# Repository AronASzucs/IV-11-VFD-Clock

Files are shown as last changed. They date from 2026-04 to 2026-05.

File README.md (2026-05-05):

<h1 align="center">IV-11 VFD Tube Clock</h1>

<p align="center">
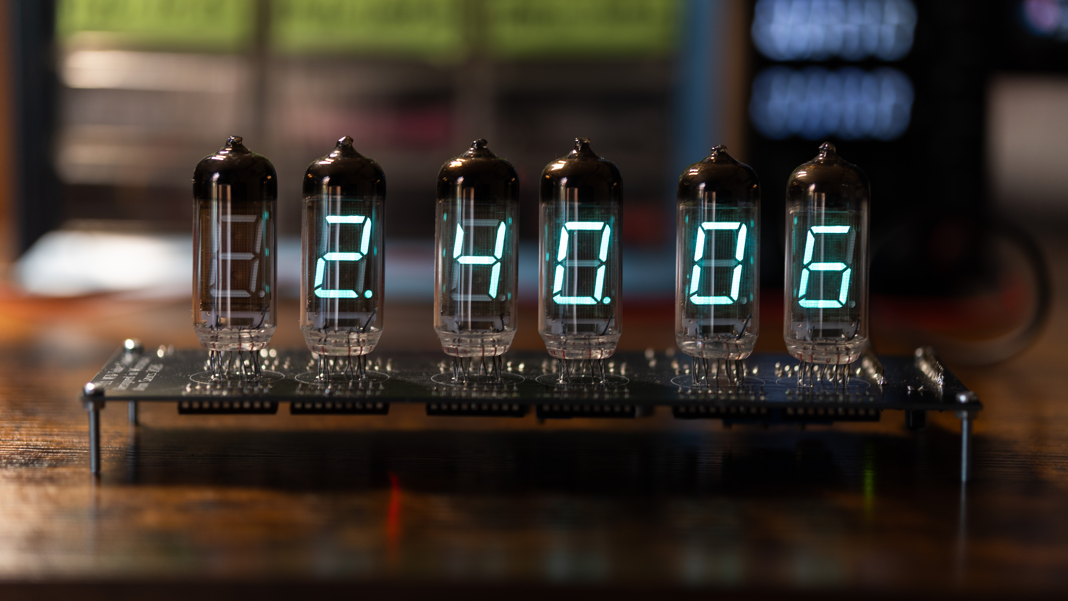
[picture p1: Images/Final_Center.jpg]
  
</p>

<p align="center">
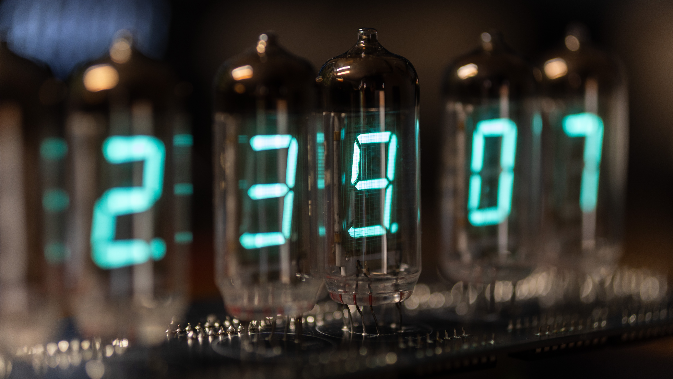
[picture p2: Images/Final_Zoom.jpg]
  
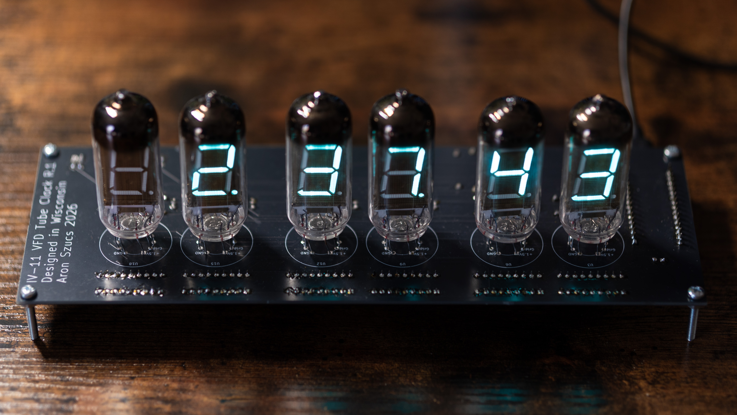
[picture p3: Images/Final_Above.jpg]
  
</p>

---

## Overview

A 6-digit clock built around Soviet-era IV-11 vacuum fluorescent display tubes, vintage components manufactured in Ukraine during the 1970s-80s. The entire project was designed from scratch, including schematic design, custom PCB layout, and firmware, with no kit or reference design used beyond architectural inspiration.

---

## Hardware

**Display**
6x IV-11 7-segment VFD tubes driven in a static configuration. One dedicated 74HC595N shift register and UDN2981A high-voltage source driver per tube, all daisy-chained via SPI. Static drive means every tube is on simultaneously at full brightness with no multiplexing.

**Power Supply**
The clock runs entirely from a 5V USB source with two onboard switching converters:
- XL6009 boost converter stepping 5V → 25V for the anode and grid rails
- LM2596 buck converter stepping 5V → 1.5V for the tube filament rails

**Timekeeping**
DS3231 real-time clock module over I2C with CR2032 battery backup. Accurate to ±2ppm and loses less than one minute per year.

**Microcontroller**
Arduino Nano Every handling SPI display control, I2C RTC communication, PWM brightness via shift register OE pin, button input with hardware debounce, and EEPROM-persistent user settings.

<p align="center">
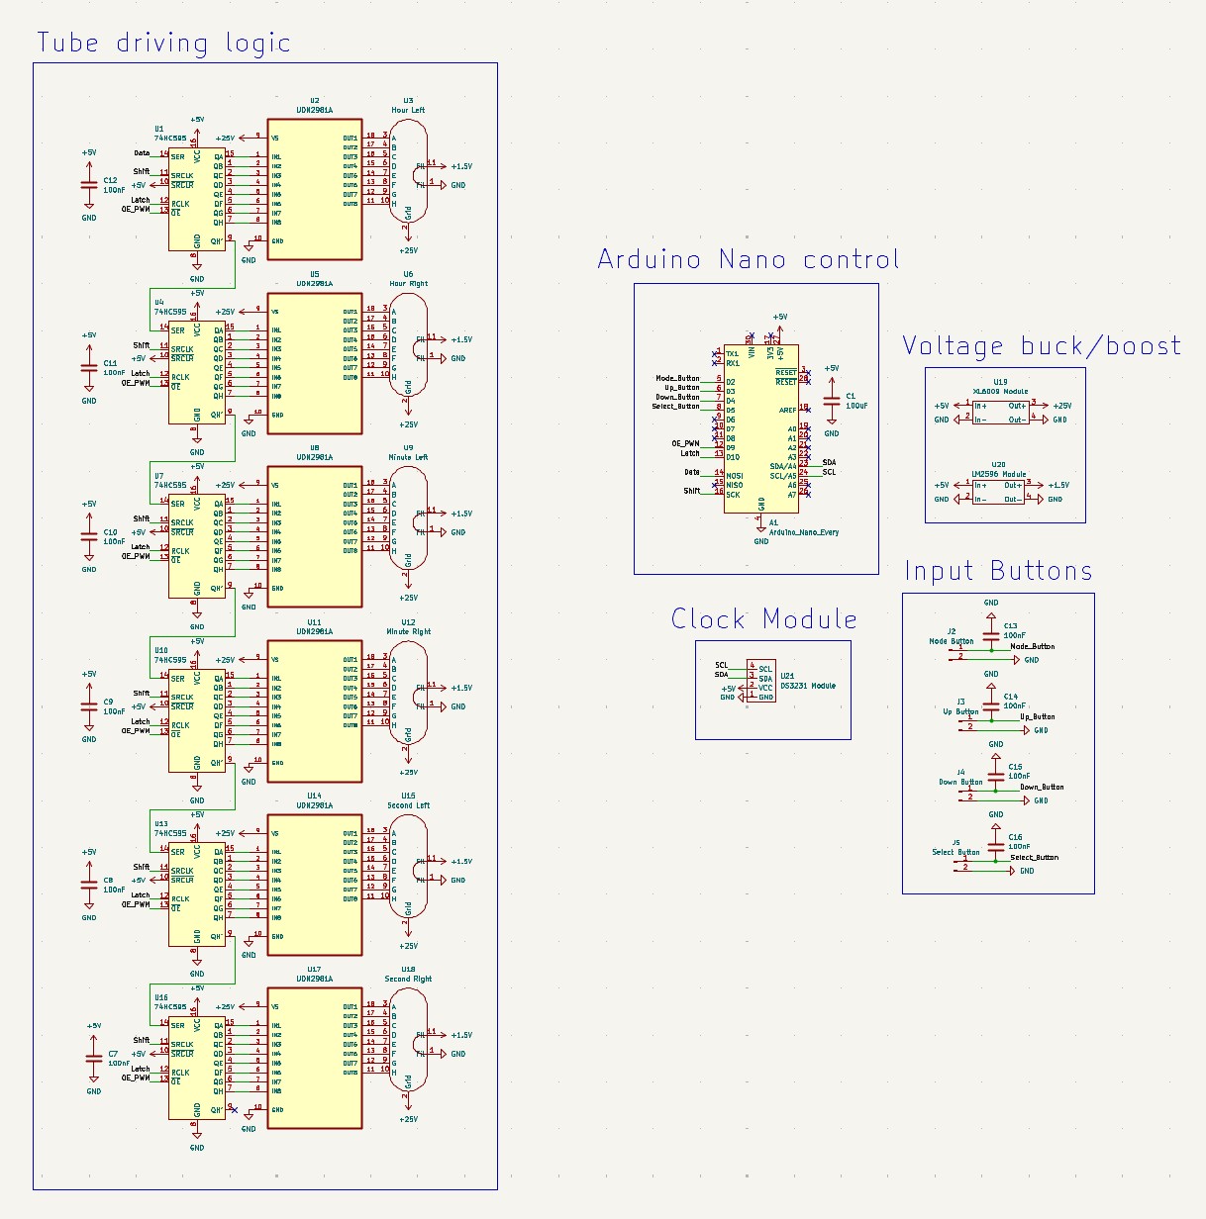
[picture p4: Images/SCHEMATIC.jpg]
  
</p>

---

## Firmware

The clock firmware implements a 7-state FSM for all user interaction:

| Mode | Function |
|---|---|
| 0 | Normal clock display |
| 1 | Set hours |
| 2 | Set minutes |
| 3 | Set seconds |
| 4 | Manual brightness (1–9) |
| 5 | Auto-brightness on/off |
| 6 | 12/24hr toggle |

Features include PWM brightness control via the 74HC595 OE pin, automatic-brightness scheduling by hour of day, hardware debounce capacitors on all button inputs, and full EEPROM persistence for brightness, auto-brightness, and 12/24hr preference across power cycles.

---

## PCB

2-layer board designed in KiCad, fabricated by JLCPCB. Custom symbols and footprints created for the IV-11 tubes, XL6009 boost converter, and LM2596 buck converter modules. Ground plane on the bottom copper layer. Power traces sized for current capacity: 1.0mm for the 600mA filament rail and 0.5mm for the 25V anode rail.

<p align="center">
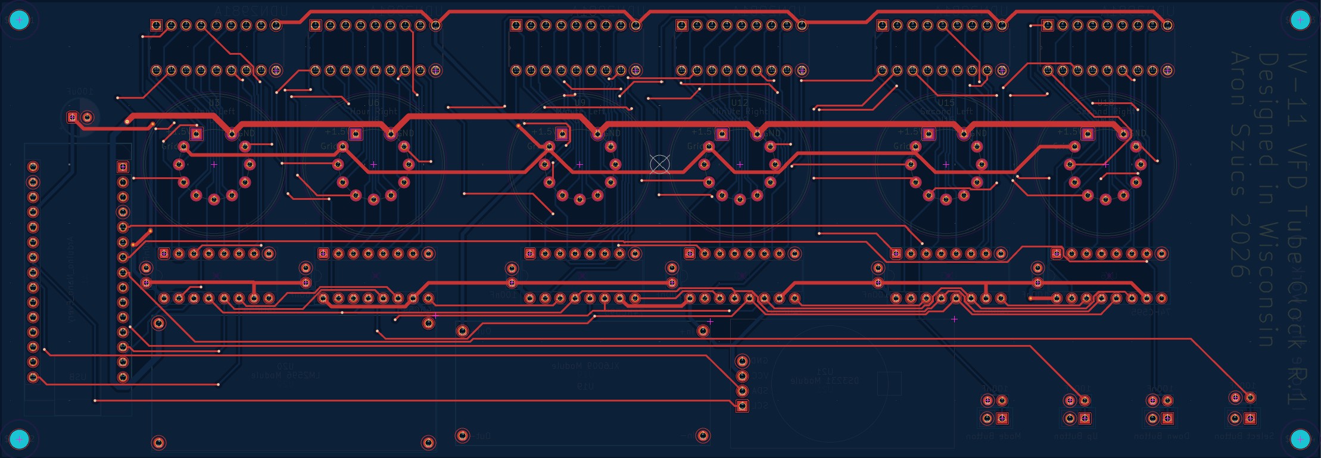
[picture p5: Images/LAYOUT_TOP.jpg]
  
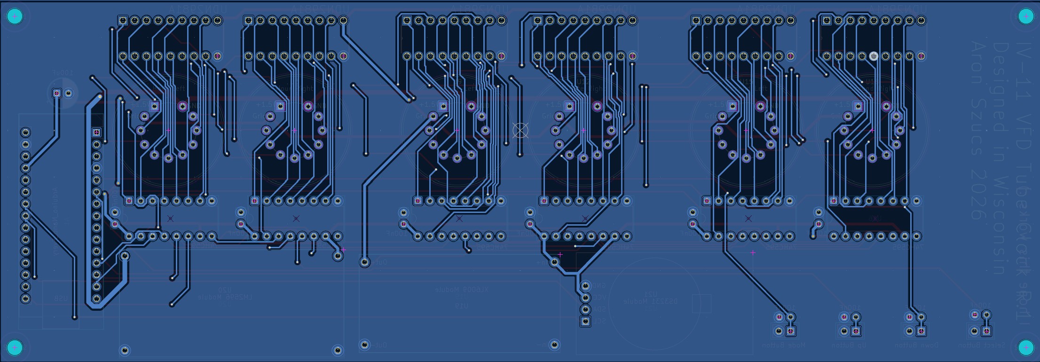
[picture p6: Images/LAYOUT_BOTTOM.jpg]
  
</p>

<p align="center">
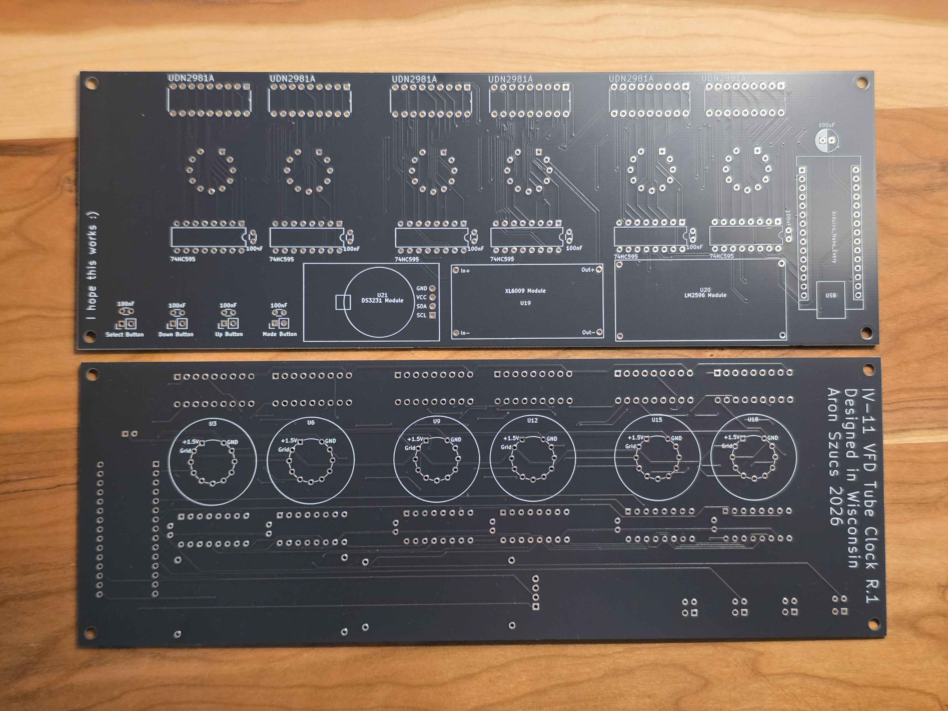
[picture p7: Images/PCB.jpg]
  
</p>

---

## Design Decisions
- I chose a static drive architecture over multiplexing for driving the VFD tubes to prioritize maximum tube brightness. Multiplexing would have reduced the total IC count substantially, but static drive increases perceived brightness and simplifies the firmware significantly.
- I used standalone pre-made buck and boost converter modules rather than integrating discrete switching converter circuits directly into the PCB to reduce design complexity on a first revision. These modules are cheap and if one fails in the future it can be swapped out easily.
- Instead of an ESP32 I used an Arduino Nano Every because this project does not require Bluetooth or WiFi. It is a simple clock after all. This did mean manual time-setting functionality needed to be implemented, which I handled by designing a 7-state FSM with full time adjustment settings. The ESP32 also runs at 3.3V which would have introduced an additional voltage level to manage.
- I encountered button signal bouncing during breadboard prototyping, so I added hardware debouncing via 100nF capacitors on each button GPIO pin in addition to software debouncing. The combination made false presses essentially nonexistent.
- I really wanted to add brightness control to my clock so it's not extremely bright at night, so I came up with the idea of toggling the output enable signal of the shift registers from a variable PWM from the Arduino Nano Every. The end result is a clean, software-driven brightness control.
- To improve signal integrity and simplify routing, I poured a solid ground plane across the entire bottom copper layer of the PCB rather than routing individual ground traces.

<p align="center">
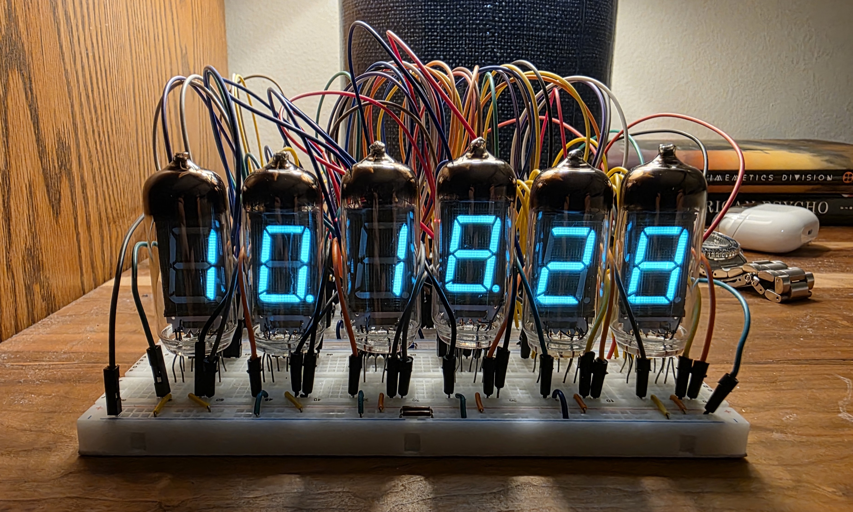
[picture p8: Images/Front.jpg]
  
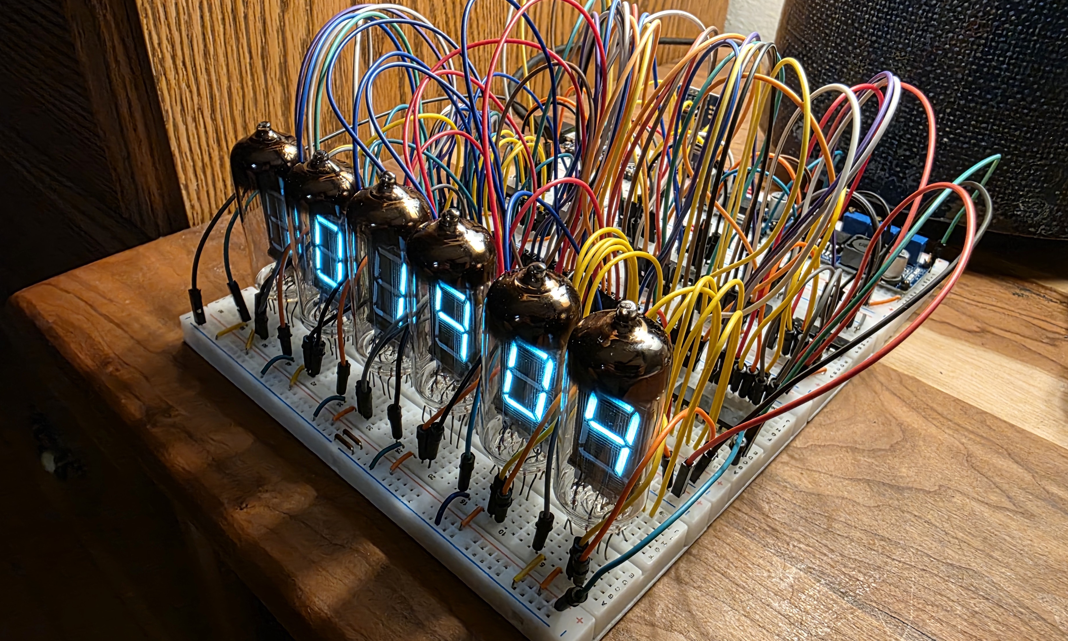
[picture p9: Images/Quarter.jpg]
  
</p>

---

## Build Notes

- The IV-11 tubes arrived from Ukraine after ~5 weeks in transit
- A tube tester utility was written to map each shift register bit to its physical segment before finalizing the digit lookup table
- The tube footprint was initially mirrored due to a bottom-view vs top-view convention mismatch in an online reference, which I caught before ordering and corrected
- This is my first major PCB design and the first revision worked flawlessly
- Production-ready Gerber files are included in the `Gerbers` folder. 

---

## Cost

| Component | Source | Cost |
|---|---|---|
| IV-11 tubes × 6 | eBay | $40.09 |
| PCB × 5 | JLCPCB | $22.84 |
| Buttons × 6 | AliExpress | $6.93 |
| Screws and hex nuts | Hardware Store | $6.25 |
| UDN2981A × 10 | AliExpress | $3.39 |
| XL6009 modules × 3 | AliExpress | $2.99 |
| DS3231 RTC module | AliExpress | $2.19 |
| LM2596 modules × 2 | AliExpress | $1.59 |
| 74HC595N × 10 | AliExpress | $1.19 |
| Arduino Nano Every | University | Free |
| Capacitors, resistors, headers | University | Free |
| **Total** | | **$87.46** |

## Acknowledgements

*Inspired by [OpenVFD](https://www.instructables.com/OpenVFD-6-Digit-IV-11-VFD-Tube-Clock/) for the static drive architecture using 74HC595 shift registers and UDN2981A source drivers.*

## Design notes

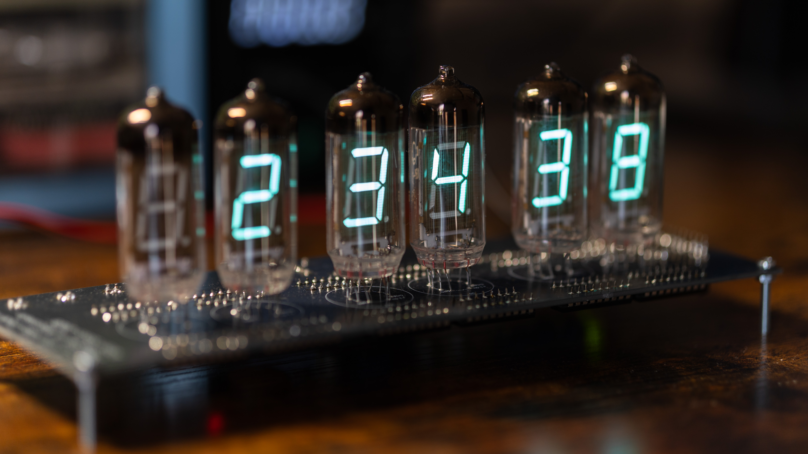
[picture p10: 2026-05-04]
Images/Final_Quarter.jpg

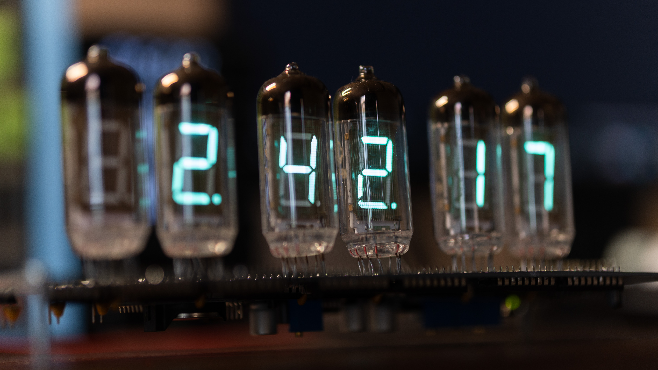
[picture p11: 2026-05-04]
Images/Final_Bottom.jpg

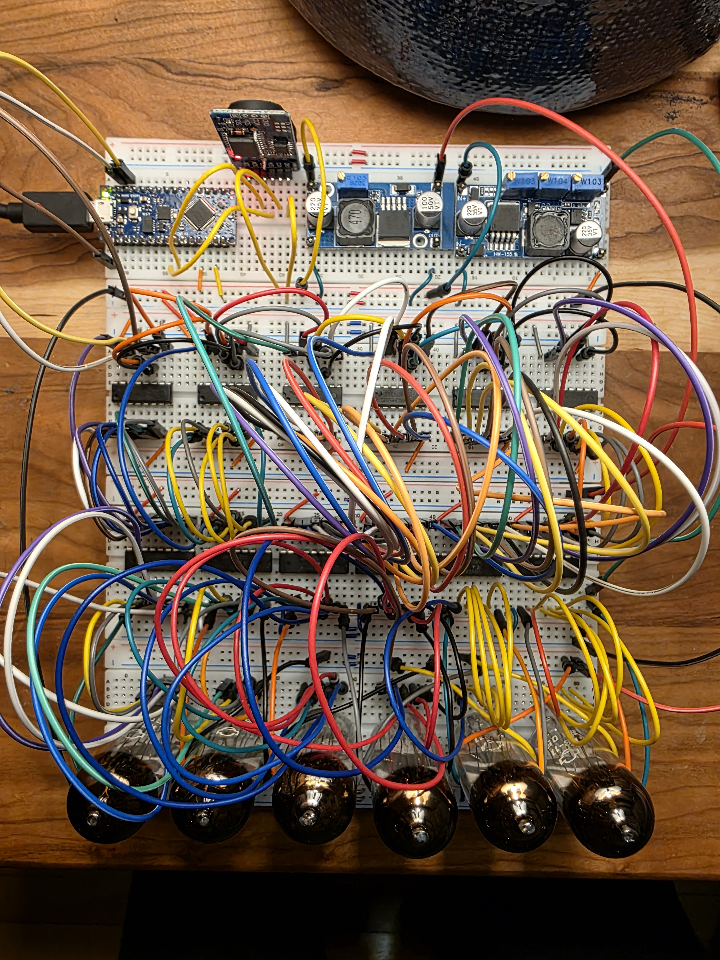
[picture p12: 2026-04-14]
Images/Above.jpg

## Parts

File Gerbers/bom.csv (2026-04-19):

Designator | Footprint | Quantity | Value | LCSC Part #
A1 | Arduino_Nano | 1 | Arduino_Nano_Every
C1 | CP_Radial_D6.3mm_P2.50mm | 1 | 100uF
C10, C11, C12, C13, C14, C15, C16, C7, C8, C9 | C_Disc_D3.0mm_W1.6mm_P2.50mm | 10 | 100nF
J2 | PinHeader_1x02_P2.54mm_Vertical | 1 | Mode Button
J3 | PinHeader_1x02_P2.54mm_Vertical | 1 | Up Button
J4 | PinHeader_1x02_P2.54mm_Vertical | 1 | Down Button
J5 | PinHeader_1x02_P2.54mm_Vertical | 1 | Select Button
U1, U10, U13, U16, U4, U7 | DIP-16_W7.62mm | 6 | 74HC595
U11, U14, U17, U2, U5, U8 | DIP254P762X533-18 | 6 | UDN2981A | UDN2981A
U12 | IV-11 VFD Tube | 1 | Minute Right
U15 | IV-11 VFD Tube | 1 | Second Left
U18 | IV-11 VFD Tube | 1 | Second Right
U19 | XL6009 Module | 1 | XL6009 Module
U20 | LM2596 Module | 1 | LM2596 Module
U21 | DS3231 Module | 1 | DS3231 Module
U3 | IV-11 VFD Tube | 1 | Hour Left
U6 | IV-11 VFD Tube | 1 | Hour Right
U9 | IV-11 VFD Tube | 1 | Minute Left

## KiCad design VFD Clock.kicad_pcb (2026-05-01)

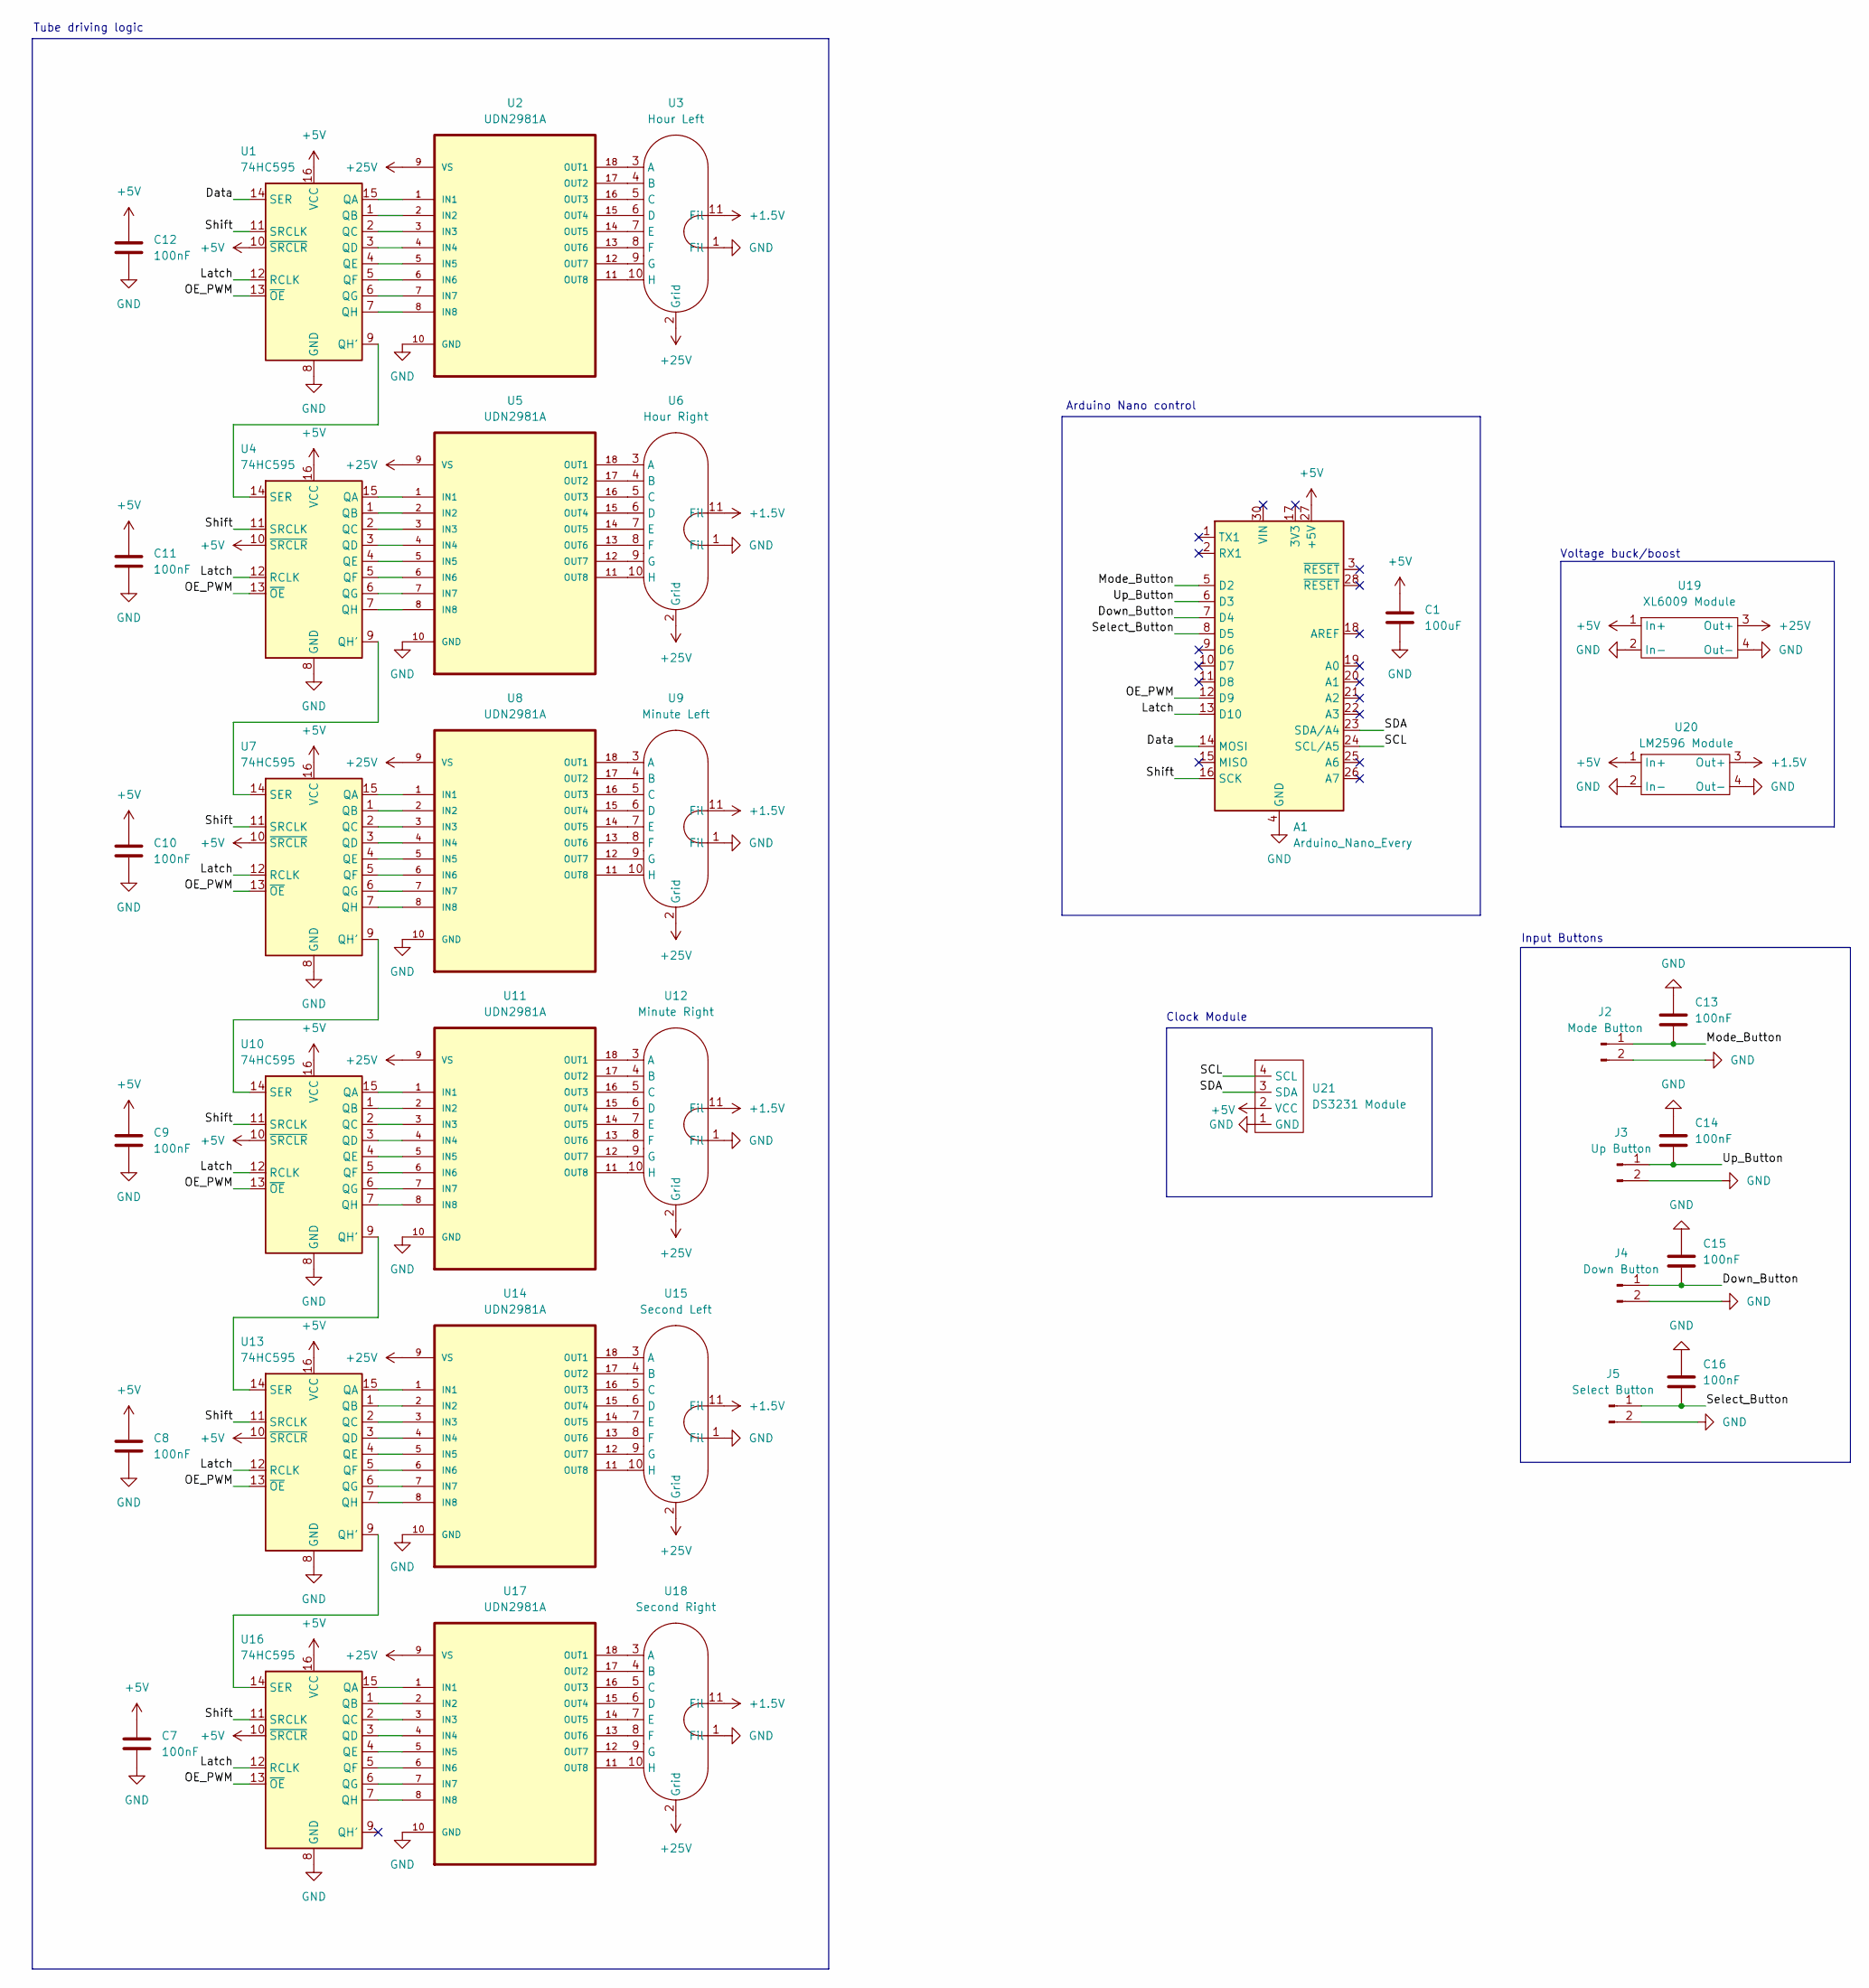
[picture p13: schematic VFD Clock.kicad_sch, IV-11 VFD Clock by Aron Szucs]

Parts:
A1: Arduino_Nano_Every; Arduino_Nano
C1: 100uF; CP_Radial_D6.3mm_P2.50mm
C7, C8, C9, C10, C11, C12, C13, C14, C15, C16: 100nF; C_Disc_D3.0mm_W1.6mm_P2.50mm
J2: Mode Button; PinHeader_1x02_P2.54mm_Vertical
J3: Up Button; PinHeader_1x02_P2.54mm_Vertical
J4: Down Button; PinHeader_1x02_P2.54mm_Vertical
J5: Select Button; PinHeader_1x02_P2.54mm_Vertical
U1, U4, U7, U10, U13, U16: 74HC595; DIP-16_W7.62mm
U2, U5, U8, U11, U14, U17: UDN2981A; DIP254P762X533-18; MPN UDN2981A
U3: Hour Left; IV-11 VFD Tube
U6: Hour Right; IV-11 VFD Tube
U9: Minute Left; IV-11 VFD Tube
U12: Minute Right; IV-11 VFD Tube
U15: Second Left; IV-11 VFD Tube
U18: Second Right; IV-11 VFD Tube
U19: XL6009 Module
U20: LM2596 Module
U21: DS3231 Module

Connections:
+1.5V: U3.11 (Fil), U6.11 (Fil), U9.11 (Fil), U12.11 (Fil), U15.11 (Fil), U18.11 (Fil), U20.3 (Out+)
+5V: A1.27 (+5V), C1.1, C7.1, C8.1, C9.1, C10.1, C11.1, C12.1, U1.10 (~SRCLR), U1.16 (VCC), U4.10 (~SRCLR), U4.16 (VCC), U7.10 (~SRCLR), U7.16 (VCC), U10.10 (~SRCLR), U10.16 (VCC), U13.10 (~SRCLR), U13.16 (VCC), U16.10 (~SRCLR), U16.16 (VCC), U19.1 (In+), U20.1 (In+), U21.2 (VCC)
+25V: U2.9 (VS), U3.2 (Grid), U5.9 (VS), U6.2 (Grid), U8.9 (VS), U9.2 (Grid), U11.9 (VS), U12.2 (Grid), U14.9 (VS), U15.2 (Grid), U17.9 (VS), U18.2 (Grid), U19.3 (Out+)
/Data: A1.14 (MOSI), U1.14 (SER)
/Down_Button: A1.7 (D4), C15.2, J4.1
/Latch: A1.13 (D10), U1.12 (RCLK), U4.12 (RCLK), U7.12 (RCLK), U10.12 (RCLK), U13.12 (RCLK), U16.12 (RCLK)
/Mode_Button: A1.5 (D2), C13.2, J2.1
/OE_PWM: A1.12 (D9), U1.13 (~OE), U4.13 (~OE), U7.13 (~OE), U10.13 (~OE), U13.13 (~OE), U16.13 (~OE)
/SCL: A1.24 (SCL/A5), U21.4 (SCL)
/SDA: A1.23 (SDA/A4), U21.3 (SDA)
/Select_Button: A1.8 (D5), C16.2, J5.1
/Shift: A1.16 (SCK), U1.11 (SRCLK), U4.11 (SRCLK), U7.11 (SRCLK), U10.11 (SRCLK), U13.11 (SRCLK), U16.11 (SRCLK)
/Up_Button: A1.6 (D3), C14.2, J3.1
GND: A1.4 (GND), A1.29 (GND), C1.2, C7.2, C8.2, C9.2, C10.2, C11.2, C12.2, C13.1, C14.1, C15.1, C16.1, J2.2, J3.2, J4.2, J5.2, U1.8 (GND), U2.10 (GND), U3.1 (Fil), U4.8 (GND), U5.10 (GND), U6.1 (Fil), U7.8 (GND), U8.10 (GND), U9.1 (Fil), U10.8 (GND), U11.10 (GND), U12.1 (Fil), U13.8 (GND), U14.10 (GND), U15.1 (Fil), U16.8 (GND), U17.10 (GND), U18.1 (Fil), U19.2 (In-), U19.4 (Out-), U20.2 (In-), U20.4 (Out-), U21.1 (GND)
unnamed: U1.15 (QA), U2.1 (IN1)
unnamed: U1.1 (QB), U2.2 (IN2)
unnamed: U1.2 (QC), U2.3 (IN3)
unnamed: U1.3 (QD), U2.4 (IN4)
unnamed: U1.4 (QE), U2.5 (IN5)
unnamed: U1.5 (QF), U2.6 (IN6)
unnamed: U1.6 (QG), U2.7 (IN7)
unnamed: U1.9 (QH'), U4.14 (SER)
unnamed: U1.7 (QH), U2.8 (IN8)
unnamed: U2.18 (OUT1), U3.3 (A)
unnamed: U2.17 (OUT2), U3.4 (B)
unnamed: U2.16 (OUT3), U3.5 (C)
unnamed: U2.15 (OUT4), U3.6 (D)
unnamed: U2.14 (OUT5), U3.7 (E)
unnamed: U2.13 (OUT6), U3.8 (F)
unnamed: U2.12 (OUT7), U3.9 (G)
unnamed: U2.11 (OUT8), U3.10 (H)
unnamed: U4.15 (QA), U5.1 (IN1)
unnamed: U4.1 (QB), U5.2 (IN2)
unnamed: U4.2 (QC), U5.3 (IN3)
unnamed: U4.3 (QD), U5.4 (IN4)
unnamed: U4.4 (QE), U5.5 (IN5)
unnamed: U4.5 (QF), U5.6 (IN6)
unnamed: U4.6 (QG), U5.7 (IN7)
unnamed: U4.9 (QH'), U7.14 (SER)
unnamed: U4.7 (QH), U5.8 (IN8)
unnamed: U5.18 (OUT1), U6.3 (A)
unnamed: U5.17 (OUT2), U6.4 (B)
unnamed: U5.16 (OUT3), U6.5 (C)
unnamed: U5.15 (OUT4), U6.6 (D)
unnamed: U5.14 (OUT5), U6.7 (E)
unnamed: U5.13 (OUT6), U6.8 (F)
unnamed: U5.12 (OUT7), U6.9 (G)
unnamed: U5.11 (OUT8), U6.10 (H)
unnamed: U7.15 (QA), U8.1 (IN1)
unnamed: U7.1 (QB), U8.2 (IN2)
unnamed: U7.2 (QC), U8.3 (IN3)
unnamed: U7.3 (QD), U8.4 (IN4)
unnamed: U7.4 (QE), U8.5 (IN5)
unnamed: U7.5 (QF), U8.6 (IN6)
unnamed: U7.6 (QG), U8.7 (IN7)
unnamed: U7.7 (QH), U8.8 (IN8)
unnamed: U8.18 (OUT1), U9.3 (A)
unnamed: U8.17 (OUT2), U9.4 (B)
unnamed: U8.16 (OUT3), U9.5 (C)
unnamed: U8.15 (OUT4), U9.6 (D)
unnamed: U8.14 (OUT5), U9.7 (E)
unnamed: U8.13 (OUT6), U9.8 (F)
unnamed: U8.12 (OUT7), U9.9 (G)
unnamed: U8.11 (OUT8), U9.10 (H)
unnamed: U10.15 (QA), U11.1 (IN1)
unnamed: U10.1 (QB), U11.2 (IN2)
unnamed: U10.2 (QC), U11.3 (IN3)
unnamed: U10.3 (QD), U11.4 (IN4)
unnamed: U10.4 (QE), U11.5 (IN5)
unnamed: U10.5 (QF), U11.6 (IN6)
unnamed: U10.6 (QG), U11.7 (IN7)
unnamed: U10.9 (QH'), U13.14 (SER)
unnamed: U10.7 (QH), U11.8 (IN8)
unnamed: U7.9 (QH'), U10.14 (SER)
unnamed: U11.18 (OUT1), U12.3 (A)
unnamed: U11.17 (OUT2), U12.4 (B)
unnamed: U11.16 (OUT3), U12.5 (C)
unnamed: U11.15 (OUT4), U12.6 (D)
unnamed: U11.14 (OUT5), U12.7 (E)
unnamed: U11.13 (OUT6), U12.8 (F)
unnamed: U11.12 (OUT7), U12.9 (G)
unnamed: U11.11 (OUT8), U12.10 (H)
unnamed: U13.15 (QA), U14.1 (IN1)
unnamed: U13.1 (QB), U14.2 (IN2)
unnamed: U13.2 (QC), U14.3 (IN3)
unnamed: U13.3 (QD), U14.4 (IN4)
unnamed: U13.4 (QE), U14.5 (IN5)
unnamed: U13.5 (QF), U14.6 (IN6)
unnamed: U13.6 (QG), U14.7 (IN7)
unnamed: U13.9 (QH'), U16.14 (SER)
unnamed: U13.7 (QH), U14.8 (IN8)
unnamed: U14.18 (OUT1), U15.3 (A)
unnamed: U14.17 (OUT2), U15.4 (B)
unnamed: U14.16 (OUT3), U15.5 (C)
unnamed: U14.15 (OUT4), U15.6 (D)
unnamed: U14.14 (OUT5), U15.7 (E)
unnamed: U14.13 (OUT6), U15.8 (F)
unnamed: U14.12 (OUT7), U15.9 (G)
unnamed: U14.11 (OUT8), U15.10 (H)
unnamed: U16.15 (QA), U17.1 (IN1)
unnamed: U16.1 (QB), U17.2 (IN2)
unnamed: U16.2 (QC), U17.3 (IN3)
unnamed: U16.3 (QD), U17.4 (IN4)
unnamed: U16.4 (QE), U17.5 (IN5)
unnamed: U16.5 (QF), U17.6 (IN6)
unnamed: U16.6 (QG), U17.7 (IN7)
unnamed: U16.7 (QH), U17.8 (IN8)
unnamed: U17.18 (OUT1), U18.3 (A)
unnamed: U17.17 (OUT2), U18.4 (B)
unnamed: U17.16 (OUT3), U18.5 (C)
unnamed: U17.15 (OUT4), U18.6 (D)
unnamed: U17.14 (OUT5), U18.7 (E)
unnamed: U17.13 (OUT6), U18.8 (F)
unnamed: U17.12 (OUT7), U18.9 (G)
unnamed: U17.11 (OUT8), U18.10 (H)

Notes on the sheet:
Arduino Nano control
Input Buttons
Clock Module
Tube driving logic
Voltage buck/boost

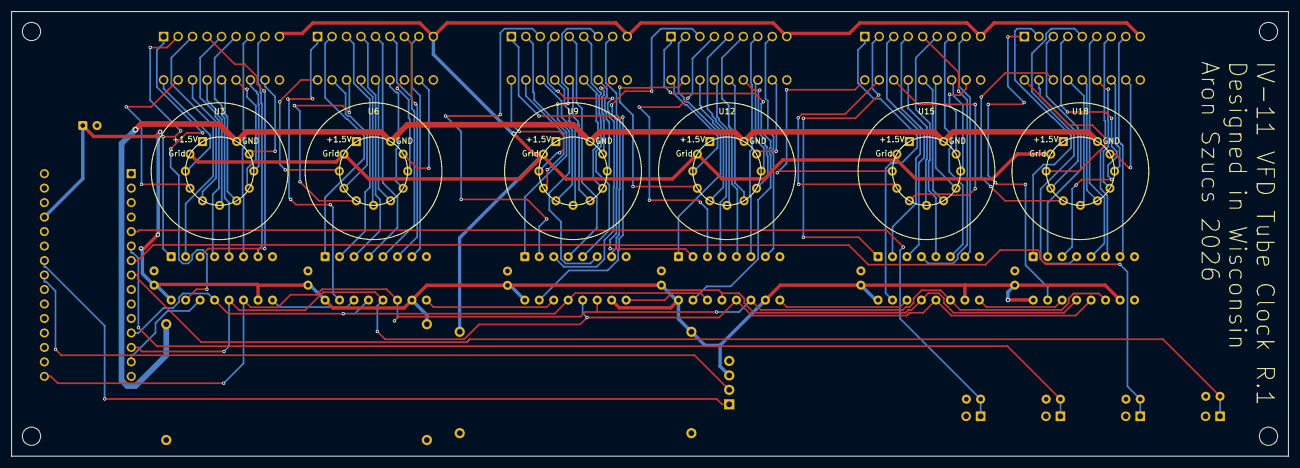
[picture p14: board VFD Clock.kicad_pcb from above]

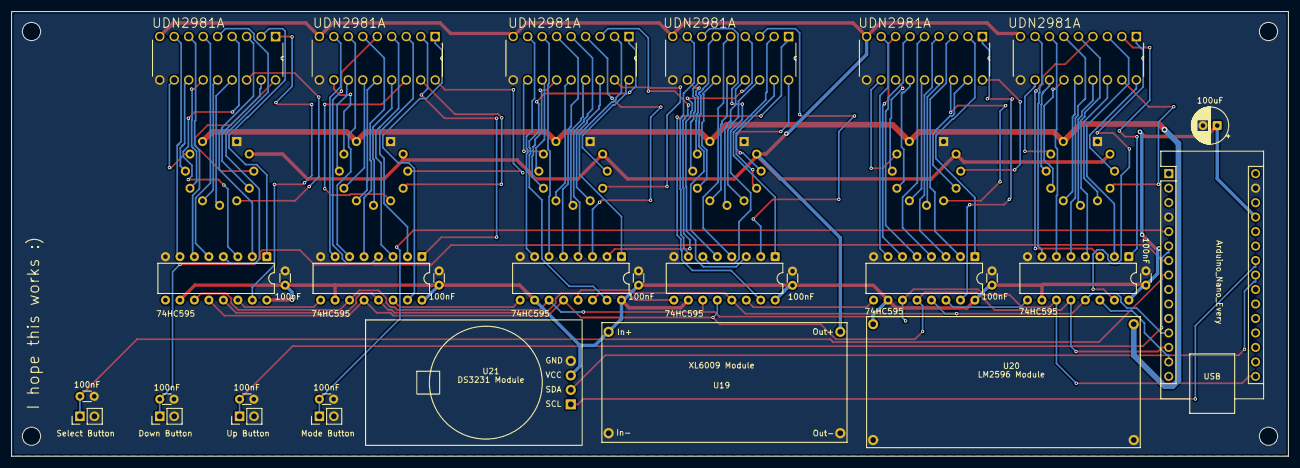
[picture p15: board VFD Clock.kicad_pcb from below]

Board: 2 copper layers, 224.0 x 78.0 mm, 41 parts (31 on the bottom side), 115 nets.

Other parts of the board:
Hole1, Hole2, Hole3, Hole4: MountingHole_3.2mm_M3

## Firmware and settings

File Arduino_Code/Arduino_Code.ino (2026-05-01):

/*
IV-11 VFD Tube Clock
code by Aron Szucs

Display Modes (SELECT in clock):
0 - HH:MM:SS
1 - MM:SS

Setting Modes (MODE cycles down chain):
0 - Normal clock
1 - Set hour
2 - Set minute
3 - Set second
4 - Set brightness (1-9, all tubes)
5 - Auto brightness (Auto t / Auto F)
6 - 12/24hr (shows 12 or 24)

SELECT on any setting → save + return to clock
SELECT on clock → toggle display mode
*/

#include <SPI.h>
#include <Wire.h>
#include <RTClib.h>
#include <EEPROM.h>

#define LATCH_PIN       10
#define PWM_PIN         9
#define MODE_BTN_PIN    2
#define UP_BTN_PIN      3
#define DOWN_BTN_PIN    4
#define SELECT_BTN_PIN  5
#define DOT_BIT         0b01000000
#define DEBOUNCE        150

#define ADDR_BRIGHTNESS  0
#define ADDR_12HR        1
#define ADDR_AUTO_BRIGHT 2

RTC_DS3231 rtc;

const int digits[] = {
  0b10110111, // 0
  0b10100000, // 1
  0b00111011, // 2
  0b10111001, // 3
  0b10101100, // 4
  0b10011101, // 5
  0b10011111, // 6
  0b10110000, // 7
  0b10111111, // 8
  0b10111101  // 9
};

const int BLANK = 0b00000000;
const int LET_A = 0b01111101;
const int LET_u = 0b11000001;
const int LET_t = 0b01110000;
const int LET_o = 0b11010001;
const int LET_F = 0b01111000;

const int brightnessLevels[] = {0, 28, 56, 84, 112, 140, 168, 196, 220, 245};

const int autoSchedule[24] = {
  230,230,230,230,230,230,
  180,100,50,20,0,0,
  0,0,0,0,0,20,
  80,150,200,220,225,230
};

int  clockMode  = 0;
int  dispMode   = 0;
int  brightness = 5;
bool use12hr    = true;
bool autoBright = false;
bool colonOn    = true;
bool editBlink  = true;
bool timeEdited = false; // tracks if user has touched time in edit mode

// live display values during edit — follow RTC until user edits
int dispHour = 0;
int dispMin  = 0;
int dispSec  = 0;

int lastMode   = HIGH;
int lastUp     = HIGH;
int lastDown   = HIGH;
int lastSelect = HIGH;

unsigned long lastUpdate     = 0;
unsigned long lastBlink      = 0;
unsigned long lastModePress  = 0;
unsigned long lastUpPress    = 0;
unsigned long lastDownPress  = 0;
unsigned long lastSelectPress= 0;

// ── EEPROM ────────────────────────────────────────────────

void loadSettings() {
  brightness = EEPROM.read(ADDR_BRIGHTNESS);
  use12hr    = EEPROM.read(ADDR_12HR);
  autoBright = EEPROM.read(ADDR_AUTO_BRIGHT);
  if (brightness < 1 || brightness > 9) brightness = 5;
  if (use12hr > 1)    use12hr    = true;
  if (autoBright > 1) autoBright = false;
  analogWrite(PWM_PIN, brightnessLevels[brightness]);
  Serial.println("=== Settings loaded ===");
  Serial.print("Brightness: ");  Serial.println(brightness);
  Serial.print("12hr: ");        Serial.println(use12hr ? "ON" : "OFF");
  Serial.print("Auto bright: "); Serial.println(autoBright ? "ON" : "OFF");
}

void saveSettings() {
  EEPROM.write(ADDR_BRIGHTNESS,  brightness);
  EEPROM.write(ADDR_12HR,        use12hr);
  EEPROM.write(ADDR_AUTO_BRIGHT, autoBright);
  Serial.println("=== Settings saved ===");
}

// ── SPI ───────────────────────────────────────────────────

void sendFrame(int t1, int t2, int t3, int t4, int t5, int t6) {
  digitalWrite(LATCH_PIN, LOW);
  SPI.transfer(t1);
  SPI.transfer(t2);
  SPI.transfer(t3);
  SPI.transfer(t4);
  SPI.transfer(t5);
  SPI.transfer(t6);
  digitalWrite(LATCH_PIN, HIGH);
}

// ── DISPLAY ───────────────────────────────────────────────

int toDisplay(int h) {
  if (use12hr) {
    if (h == 0) h = 12;
    else if (h > 12) h -= 12;
  }
  return h;
}

void displayClock(int h, int m, int s) {
  h = toDisplay(h);
  int dot = colonOn ? DOT_BIT : 0;
  if (dispMode == 0) {
    sendFrame(h/10 ? digits[h/10] : BLANK, digits[h%10]|dot, digits[m/10], digits[m%10]|dot, digits[s/10], digits[s%10]);
  } else {
    sendFrame(BLANK, BLANK, digits[m/10], digits[m%10]|dot, digits[s/10], digits[s%10]);
  }
}

void displayTimeEdit(int h, int m, int s) {
  h = toDisplay(h);
  int dot = colonOn ? DOT_BIT : 0;
  int h1 = h/10 ? digits[h/10] : BLANK;
  int h2 = digits[h%10]|dot;
  int m1 = digits[m/10];
  int m2 = digits[m%10]|dot;
  int s1 = digits[s/10];
  int s2 = digits[s%10];
  if (!editBlink) {
    if (clockMode == 1) { h1 = BLANK; h2 = BLANK; }
    if (clockMode == 2) { m1 = BLANK; m2 = BLANK; }
    if (clockMode == 3) { s1 = BLANK; s2 = BLANK; }
  }
  sendFrame(h1, h2, m1, m2, s1, s2);
}

void displayBrightness() {
  int d = digits[brightness];
  sendFrame(d, d, d, d, d, d);
}

void displayAutoBright() {
  sendFrame(LET_A, LET_u, LET_t, LET_o, BLANK, autoBright ? LET_t : LET_F);
}

void display1224() {
  int tens = use12hr ? digits[1] : digits[2];
  int ones = use12hr ? digits[2] : digits[4];
  sendFrame(BLANK, BLANK, tens, ones, BLANK, BLANK);
}

void handleDisplay() {
  DateTime t = rtc.now();
  if (autoBright && clockMode == 0) analogWrite(PWM_PIN, autoSchedule[t.hour()]);

  switch (clockMode) {
    case 0:
      displayClock(t.hour(), t.minute(), t.second());
      break;
    case 1: case 2: case 3:
      // if not yet edited by user, follow live RTC time
      if (!timeEdited) {
        dispHour = t.hour();
        dispMin  = t.minute();
        dispSec  = t.second();
      }
      displayTimeEdit(dispHour, dispMin, dispSec);
      break;
    case 4: displayBrightness();  break;
    case 5: displayAutoBright();  break;
    case 6: display1224();        break;
  }
}

// ── BUTTONS ───────────────────────────────────────────────

void handleButtons() {
  int modeBtn   = digitalRead(MODE_BTN_PIN);
  int upBtn     = digitalRead(UP_BTN_PIN);
  int downBtn   = digitalRead(DOWN_BTN_PIN);
  int selectBtn = digitalRead(SELECT_BTN_PIN);
  unsigned long now = millis();

  // MODE — advance chain
  if (modeBtn == LOW && lastMode == HIGH && now - lastModePress > DEBOUNCE) {
    lastModePress = now;
    if (clockMode == 0) {
      // snapshot RTC as starting point for edit
      DateTime t = rtc.now();
      dispHour   = t.hour();
      dispMin    = t.minute();
      dispSec    = t.second();
      timeEdited = false;
    }
    clockMode = (clockMode + 1) % 7;
    Serial.print("Mode → "); Serial.println(clockMode);
  }

  // SELECT — toggle display in clock, save + exit in settings
  if (selectBtn == LOW && lastSelect == HIGH && now - lastSelectPress > DEBOUNCE) {
    lastSelectPress = now;
    if (clockMode == 0) {
      dispMode = (dispMode + 1) % 2;
      Serial.print("Display mode → "); Serial.println(dispMode);
    } else {
      if (clockMode >= 1 && clockMode <= 3 && timeEdited) {
        DateTime t = rtc.now();
        rtc.adjust(DateTime(t.year(), t.month(), t.day(), dispHour, dispMin, dispSec));
        Serial.print("Time saved → ");
        Serial.print(dispHour); Serial.print(":"); Serial.print(dispMin); Serial.print(":"); Serial.println(dispSec);
      } else if (clockMode >= 1 && clockMode <= 3 && !timeEdited) {
        Serial.println("No edit made — time unchanged");
      }
      if (clockMode >= 4) saveSettings();
      timeEdited = false;
      clockMode  = 0;
      Serial.println("→ clock");
    }
  }

  // UP
  if (upBtn == LOW && lastUp == HIGH && now - lastUpPress > DEBOUNCE) {
    lastUpPress = now;
    if (clockMode >= 1 && clockMode <= 3) {
      // snapshot RTC on first edit so we start from current time
      if (!timeEdited) {
        DateTime t = rtc.now();
        dispHour   = t.hour();
        dispMin    = t.minute();
        dispSec    = t.second();
        timeEdited = true;
      }
    }
    if      (clockMode == 1) { dispHour   = (dispHour  + 1)  % 24; Serial.print("Hour: ");       Serial.println(dispHour); }
    else if (clockMode == 2) { dispMin    = (dispMin   + 1)  % 60; Serial.print("Min: ");        Serial.println(dispMin); }
    else if (clockMode == 3) { dispSec    = (dispSec   + 1)  % 60; Serial.print("Sec: ");        Serial.println(dispSec); }
    else if (clockMode == 4) { brightness = min(brightness + 1, 9); analogWrite(PWM_PIN, brightnessLevels[brightness]); Serial.print("Brightness: "); Serial.println(brightness); }
    else if (clockMode == 5) { autoBright = !autoBright; Serial.print("Auto: "); Serial.println(autoBright ? "ON" : "OFF"); }
    else if (clockMode == 6) { use12hr    = !use12hr;    Serial.print("12hr: "); Serial.println(use12hr ? "ON" : "OFF"); }
  }

  // DOWN
  if (downBtn == LOW && lastDown == HIGH && now - lastDownPress > DEBOUNCE) {
    lastDownPress = now;
    if (clockMode >= 1 && clockMode <= 3) {
      if (!timeEdited) {
        DateTime t = rtc.now();
        dispHour   = t.hour();
        dispMin    = t.minute();
        dispSec    = t.second();
        timeEdited = true;
      }
    }
    if      (clockMode == 1) { dispHour   = (dispHour  + 23) % 24; Serial.print("Hour: ");       Serial.println(dispHour); }
    else if (clockMode == 2) { dispMin    = (dispMin   + 59) % 60; Serial.print("Min: ");        Serial.println(dispMin); }
    else if (clockMode == 3) { dispSec    = (dispSec   + 59) % 60; Serial.print("Sec: ");        Serial.println(dispSec); }
    else if (clockMode == 4) { brightness = max(brightness - 1, 1); analogWrite(PWM_PIN, brightnessLevels[brightness]); Serial.print("Brightness: "); Serial.println(brightness); }
    else if (clockMode == 5) { autoBright = !autoBright; Serial.print("Auto: "); Serial.println(autoBright ? "ON" : "OFF"); }
    else if (clockMode == 6) { use12hr    = !use12hr;    Serial.print("12hr: "); Serial.println(use12hr ? "ON" : "OFF"); }
  }

  lastMode   = modeBtn;
  lastUp     = upBtn;
  lastDown   = downBtn;
  lastSelect = selectBtn;
}

// ── SETUP ─────────────────────────────────────────────────

void setup() {
  Serial.begin(9600);
  pinMode(LATCH_PIN, OUTPUT);
  digitalWrite(LATCH_PIN, HIGH);
  pinMode(PWM_PIN, OUTPUT);
  pinMode(MODE_BTN_PIN,   INPUT_PULLUP);
  pinMode(UP_BTN_PIN,     INPUT_PULLUP);
  pinMode(DOWN_BTN_PIN,   INPUT_PULLUP);
  pinMode(SELECT_BTN_PIN, INPUT_PULLUP);

  SPI.begin();
  SPI.beginTransaction(SPISettings(500000, LSBFIRST, SPI_MODE0));
  Wire.begin();
  loadSettings();

  if (!rtc.begin()) {
    Serial.println("ERROR: RTC not found");
    while (1) {
      sendFrame(0xFF,0xFF,0xFF,0xFF,0xFF,0xFF); delay(200);
      sendFrame(0x00,0x00,0x00,0x00,0x00,0x00); delay(200);
    }
  }

  DateTime t = rtc.now();
  Serial.print("=== IV-11 Clock started: ");
  Serial.print(t.hour()); Serial.print(":"); Serial.print(t.minute()); Serial.print(":"); Serial.println(t.second());
}

// ── LOOP ──────────────────────────────────────────────────

void loop() {
  handleButtons();

  // blink — redraws edit modes immediately so blink is responsive
  if (millis() - lastBlink >= 500) {
    lastBlink = millis();
    editBlink = !editBlink;
    if (clockMode >= 1 && clockMode <= 3) handleDisplay();
  }

  // 1 second tick
  if (millis() - lastUpdate >= 1000) {
    lastUpdate = millis();
    colonOn = !colonOn;
    handleDisplay();
  }
}

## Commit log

2026-04-12 small updates
    [VFD Clock.kicad_sch]
2026-04-12 added arduino nano
    [VFD Clock.kicad_sch]
2026-04-12 created symbol for custom iv-11 part
    [VFD Clock.kicad_sch]
2026-04-12 struggling to link symbol and footprint
2026-04-12 fixed symbol/footprint linking, working on schematic
    [VFD Clock.kicad_sch]
2026-04-13 finished lm2596 module footprint
2026-04-13 omg I finally figured out how to link the UDN2981A symbol and footprint I am the goat
    [VFD Clock.kicad_sch]
2026-04-13 added OE PWM functionality to control the brightness of every tube using software
    [VFD Clock.kicad_sch]
2026-04-13 added buttons, power LED, and more
    [VFD Clock.kicad_sch]
2026-04-14 added arduino code and fixed schematic bug
    [VFD Clock.kicad_sch]
2026-04-14 Update README with detailed project information
    Expanded project description for the IV-11 VFD clock, detailing components and current progress.
2026-04-14 started prototyping pcb layout
    [VFD Clock.kicad_pcb, VFD Clock.kicad_sch]
2026-04-15 schematic edit
    [VFD Clock.kicad_sch]
2026-04-15 pcb layout updates. Locked in the tube positions
    [VFD Clock.kicad_pcb, VFD Clock.kicad_sch]
2026-04-16 PCB layout changes
    [VFD Clock.kicad_pcb, VFD Clock.kicad_sch]
2026-04-16 pcb layout
    [VFD Clock.kicad_pcb]
2026-04-16 minor changes
    [VFD Clock.kicad_pcb, VFD Clock.kicad_sch]
2026-04-16 Created custom ds3231 module and added it to schematic and pcb
    [VFD Clock.kicad_pcb, VFD Clock.kicad_sch]
2026-04-16 close to finishing pcb
    [VFD Clock.kicad_pcb]
2026-04-16 mounting holes
    [VFD Clock.kicad_pcb]
2026-04-17 removed all tracks, starting over
    [VFD Clock.kicad_pcb]
2026-04-18 add debouncing caps
    [VFD Clock.kicad_pcb, VFD Clock.kicad_sch]
2026-04-18 schematic ordering
    [VFD Clock.kicad_sch]
2026-04-18 GND pour
    [VFD Clock.kicad_pcb]
2026-04-18 IV-11 Tube footprint was flipped, unflipped it
    [VFD Clock.kicad_pcb]
2026-04-18 maybe good routing
    [VFD Clock.kicad_pcb]
2026-04-19 adding hoppefully working one
    [VFD Clock.kicad_pcb, bom.csv, designators.csv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]
2026-04-19 DFM check tweaks
    [VFD Clock.kicad_pcb]
2026-05-01 fixed tube code for PCB clock
    [VFD Clock.kicad_pcb]
2026-05-04 Added final PCB images
2026-05-04 add images
    [VFD Clock.kicad_sch]
2026-05-04 Add PCB layout images to README
2026-05-04 Include PCB image in README
    Add PCB image to the README for better visualization.
2026-05-04 clean up
    [bom.csv, designators.csv, positions.csv]
2026-05-05 Add Schematic img
